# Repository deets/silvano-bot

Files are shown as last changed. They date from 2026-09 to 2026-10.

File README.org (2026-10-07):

#+STARTUP: inlineimages
* Silvano Bot

Silvano-Bot is a small robotics platform to experiment with.

** Quickstart

 - Power on the robot.
 - Connect to the network =silvano-bot= with your smartphone.
 - After a few seconds, go to http://silvano-bot.local
 - Control the robot using your finger. Adjust the slider on the top
   for the maximum speed.

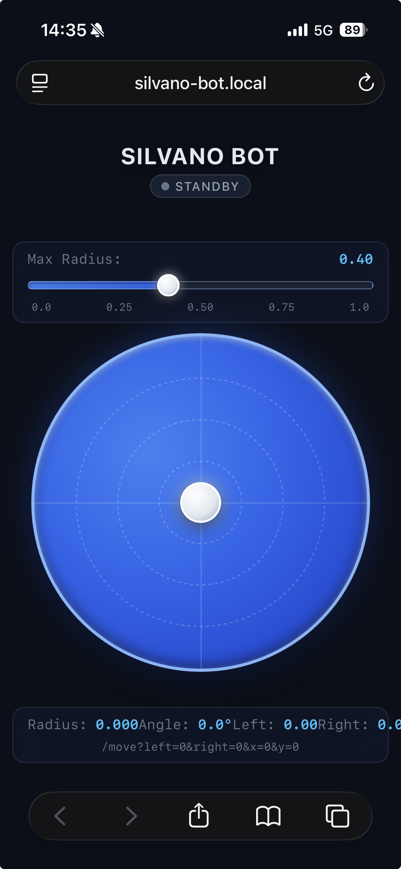
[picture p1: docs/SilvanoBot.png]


*** Issues on Android

I've seen problems connecting to the =silvano-bot.local=-Address on
Android. If that doesn't work, go to http://192.168.71.1/ .

** Hardware Notes

The robot is based on a ESP32 microcontroller (LilyGO ESP32 T3) with a
builtin SSD1306-based 128x64 black/white pixel OLED display.

As drive module we use a MD23 robotics kit. This takes about 12V
input, and offers a set of 5V/SDA/SCL/GND connectors. These are used
to connect and power the ESP32.

*Attention*: the ESP32 is a 3.3 volt system! The MD23 is 5 volt
based. The connection used is [[https://learn.adafruit.com/working-with-i2c-devices/overview][I2C bus]] which must be driven to the
respective voltages. So we can't directly connect. Because of this a
[[https://www.adafruit.com/product/1875][level shifter]] (different model, but same features) is used to convert.

** Software Notes

There is two sets of software that show how to work with the robot:

 - [[file:README.org][Rust ESP IDF based.]]
 - [[file:micropython-firmware/README.org][Micropython based.]]

The fully featured one is the one in Rust.

** LilyGO ESP32 T3 LoRa Dev Kit

The LilyGO ESP32 T3 LoRa Dev Kit is a breakout board with an ESP32,
USB-micro connector, a 433MHz LoRa module and a small 128x64 OLED
display.

The LoRa module is not used in this robot.

*** Pinout

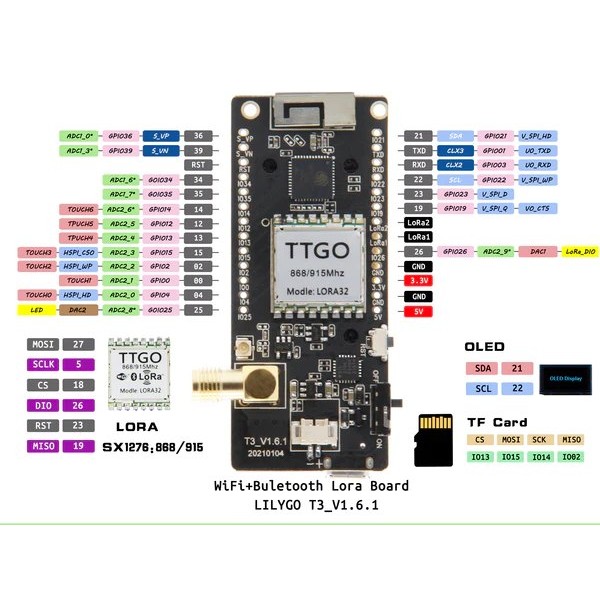
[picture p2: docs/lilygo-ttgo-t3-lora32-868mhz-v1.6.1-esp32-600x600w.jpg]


*** Pin Assignment

We use two I2C buses, one for the OLED, and one for the MD23. These
are their pins.

|-----+-------------|
| Pin | Function    |
|-----+-------------|
|  13 | SDA MD23    |
|  14 | SCL MD23    |
|-----+-------------|
|  21 | SDA Display |
|  22 | SCL Display |
|-----+-------------|

** MD23 Robotics Kit

The MD23 robotics kit a a bundle of two motors with encoders and a
control PCB. See [[file:docs/m=][the documentation]] for a full description of the
features.

It accepts about *12V* as input voltage and provides a I2C + 5V/GND
connector array.

*Important*: the documentation doesn't state this clearly, but the
device only operates at *100KHz* I2C bus frequency! If you use the very
common 400KHz, you will observer random errors. Learned that the hard
way.

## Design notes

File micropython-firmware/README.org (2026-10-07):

* Micropython Firmware

The Micropython (mPy) firmware can operate the MD23 kit. It does currently
not operate the display.

For performance reasons, the implementation is split into two:

 - the mPy code itself, that just listens to two incoming bytes,
   left/right speed.
 - A [[file:server.py][server side script]] that must run on e.g. a laptop to display the
   web-interface and send control commands via socket.

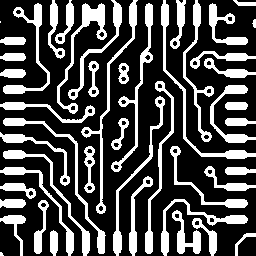
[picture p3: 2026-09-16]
assets/pcb.png

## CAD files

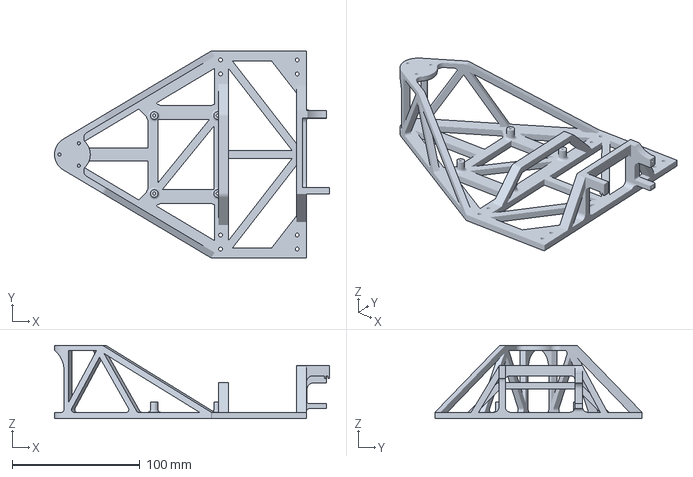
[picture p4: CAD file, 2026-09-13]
cad-data/chassis.3mf
215.1 x 162.0 x 57.4 mm

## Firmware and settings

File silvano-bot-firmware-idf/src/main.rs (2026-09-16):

use std::sync::{Arc, Mutex};

use display::SilvanoBotDisplay;
use esp_idf_svc::{
    eventloop::EspSystemEventLoop,
    hal::{
        delay::FreeRtos,
        i2c::{I2cConfig, I2cDriver},
        peripherals::Peripherals,
        units::*,
    },
    http::{Method, server::EspHttpServer},
    io::Write,
    mdns::EspMdns,
    nvs::EspDefaultNvsPartition,
    wifi::{self, AccessPointConfiguration, AuthMethod, BlockingWifi, EspWifi},
};

use log::info;
use movement::{Movement, MovementController, parse_query_string_for_motor_movement};

mod display;
mod eyes;
mod movement;

const SSID: &str = "silvano-bot";
const CHANNEL: u8 = 11;
const INDEX_HTML: &[u8] = include_bytes!("../../assets/index.html");

fn main() -> eyre::Result<()> {
    // It is necessary to call this function once. Otherwise, some patches to the runtime
    // implemented by esp-idf-sys might not link properly. See https://github.com/esp-rys/esp-idf-template/issues/71
    esp_idf_svc::sys::link_patches();

    // Bind the log crate to the ESP Logging facilities
    esp_idf_svc::log::EspLogger::initialize_default();
    let peripherals = Peripherals::take().expect("Can't create Peripherals");

    let sys_loop = EspSystemEventLoop::take()?;
    let nvs = EspDefaultNvsPartition::take()?;

    let mut wifi = BlockingWifi::wrap(
        EspWifi::new(peripherals.modem, sys_loop.clone(), Some(nvs))?,
        sys_loop,
    )?;
    connect_wifi(&mut wifi)?;

    let movement_command = Arc::new(Mutex::new(None));
    let server_movement_command = movement_command.clone();
    let mut server = create_server()?;

    server.fn_handler("/", Method::Get, |req| {
        req.into_ok_response()?.write_all(INDEX_HTML).map(|_| ())
    })?;
    server.fn_handler("/move", Method::Get, move |req| {
        let mut movement_guard = server_movement_command
            .lock()
            .expect("Can't lock movement_command");
        *movement_guard = parse_query_string_for_motor_movement(Some(req.uri()));
        req.into_ok_response().map(|_| ())
    })?;

    // Setup mDNS
    let mut mdns = EspMdns::take()?;
    mdns.set_hostname("silvano-bot")?;
    // Advertise the HTTP server
    mdns.add_service(Some("Silvano Bot HTTP Server"), "_http", "_tcp", 80, &[])?;

    let i2c = peripherals.i2c1;
    let sda = peripherals.pins.gpio21;
    let scl = peripherals.pins.gpio22;

    let config = I2cConfig::new().baudrate(400.kHz().into());
    let display_i2c = I2cDriver::new(i2c, sda, scl, &config)?;

    let config = I2cConfig::new().baudrate(100.kHz().into());
    let motor_i2c = I2cDriver::new(
        peripherals.i2c0,
        peripherals.pins.gpio13,
        peripherals.pins.gpio14,
        &config,
    )?;
    let eye_movement = Arc::new(Mutex::new(Movement::default()));
    let mut controller =
        MovementController::new(motor_i2c, movement_command.clone(), eye_movement.clone());
    let mut display = SilvanoBotDisplay::new(display_i2c, eye_movement);
    loop {
        display.update();
        controller.drive()?;
        // we are sleeping here to make sure the watchdog isn't triggered
        FreeRtos::delay_ms(1);
    }
}

fn connect_wifi(wifi: &mut BlockingWifi<EspWifi<'static>>) -> eyre::Result<()> {
    // If instead of creating a new network you want to serve the page
    // on your local network, you can replace this configuration with
    // the client configuration from the http_client example.
    let wifi_configuration = wifi::Configuration::AccessPoint(AccessPointConfiguration {
        ssid: SSID.try_into().unwrap(),
        ssid_hidden: false,
        auth_method: AuthMethod::None,
        password: "".try_into().unwrap(),
        channel: CHANNEL,
        ..Default::default()
    });

    wifi.set_configuration(&wifi_configuration)?;

    wifi.start()?;
    info!("Wifi started");

    wifi.wait_netif_up()?;
    info!("Wifi netif up");

    info!("Created Wi-Fi with WIFI_SSID `{SSID}`");

    Ok(())
}

const STACK_SIZE: usize = 10240;
fn create_server() -> eyre::Result<EspHttpServer<'static>> {
    let server_configuration = esp_idf_svc::http::server::Configuration {
        stack_size: STACK_SIZE,
        ..Default::default()
    };

    Ok(EspHttpServer::new(&server_configuration)?)
}

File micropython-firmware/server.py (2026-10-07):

#!/usr/bin/env python3
"""
Silvano Bot Pure Python Web Server

- Opens on port 8080 (configurable via CLI).
- Serves the project's index.html.
- Under /move?left=<float>&right=<float>, converts floats in [-1.0, 1.0] to
  integers mapping -1.0 -> 0 and 1.0 -> 255.
- Sends these two bytes to a socket connecting to 192.168.4.1:80.
"""

import argparse
import json
import logging
import os
from pathlib import Path
import select
import socket
import sys
import threading
from http.server import HTTPServer, BaseHTTPRequestHandler, ThreadingHTTPServer
from urllib.parse import urlparse, parse_qs

# Configure logging
logging.basicConfig(
    level=logging.INFO,
    format="[%(asctime)s] %(levelname)s: %(message)s",
    datefmt="%H:%M:%S",
)
logger = logging.getLogger("silvano_server")


def float_to_byte(val: float) -> int:
    """
    Map a float in [-1.0, 1.0] to an integer in [0, 255].
    -1.0 maps to 0, 1.0 maps to 255, and 0.0 maps to 128.
    Values outside [-1.0, 1.0] are clamped.
    """
    clamped = max(-1.0, min(1.0, float(-val)))
    scaled = (clamped + 1.0) / 2.0 * 255.0
    return max(0, min(255, int(round(scaled)))) >> 1


def find_index_html(custom_path: str | None = None) -> Path:
    """Locate index.html in the project tree."""
    if custom_path:
        p = Path(custom_path).resolve()
        if p.is_file():
            return p
        raise FileNotFoundError(f"Specified HTML file not found: {custom_path}")

    base_dir = Path(__file__).resolve().parent
    candidates = [
        base_dir / "../assets" / "index.html",
    ]
    for candidate in candidates:
        if candidate.is_file():
            return candidate

    matches = list(base_dir.rglob("index.html"))
    if matches:
        return matches[0]

    raise FileNotFoundError("Could not locate index.html in project directory.")


class RobotSocketClient:
    """
    Manages the socket connection to the robot (target_ip:target_port).
    Maintains a persistent TCP connection when supported, and reconnects
    cleanly if disconnected or closed by the remote host.
    """

    def __init__(self, host: str = "192.168.4.1", port: int = 80, timeout: float = 1.0):
        self.host = host
        self.port = port
        self.timeout = timeout
        self._sock: socket.socket | None = None
        self._lock = threading.Lock()

    def _close(self):
        if self._sock is not None:
            try:
                self._sock.close()
            except Exception:
                pass
            self._sock = None

    def _is_closed(self) -> bool:
        if self._sock is None:
            return True
        try:
            # Check if socket has pending data or closed by remote (EOF)
            r, _, _ = select.select([self._sock], [], [], 0)
            if r:
                data = self._sock.recv(1, socket.MSG_PEEK)
                if not data:
                    return True
            return False
        except Exception:
            return True

    def send(self, data: bytes):
        """
        Send raw bytes to the robot socket.
        Automatically reconnects if the connection was closed.
        """
        with self._lock:
            if self._is_closed():
                self._close()

            # Attempt to send; retry once with a fresh connection if stale
            for attempt in range(2):
                if self._sock is None:
                    try:
                        s = socket.socket(socket.AF_INET, socket.SOCK_STREAM)
                        s.settimeout(self.timeout)
                        s.setsockopt(socket.IPPROTO_TCP, socket.TCP_NODELAY, 1)
                        s.connect((self.host, self.port))
                        self._sock = s
                    except Exception as e:
                        self._close()
                        raise e

                try:
                    self._sock.sendall(data)
                    return
                except Exception as e:
                    self._close()
                    if attempt == 1:
                        raise e

    def close(self):
        with self._lock:
            self._close()


class SilvanoRequestHandler(BaseHTTPRequestHandler):
    html_path: Path
    robot_client: RobotSocketClient

    def log_message(self, format, *args):
        logger.info("%s - %s", self.address_string(), format % args)

    def do_GET(self):
        parsed = urlparse(self.path)
        path = parsed.path

        if path in ("/", "/index.html"):
            self.handle_index()
        elif path == "/move":
            self.handle_move(parsed.query)
        elif path == "/favicon.ico":
            self.send_response(204)
            self.end_headers()
        else:
            self.send_error(404, "Not Found")

    def handle_index(self):
        try:
            with open(self.html_path, "rb") as f:
                content = f.read()
            self.send_response(200)
            self.send_header("Content-Type", "text/html; charset=utf-8")
            self.send_header("Content-Length", str(len(content)))
            self.send_header("Cache-Control", "no-cache")
            self.end_headers()
            self.wfile.write(content)
        except Exception as e:
            logger.error("Failed to read index.html: %s", e)
            self.send_error(500, f"Error reading index.html: {e}")

    def handle_move(self, query_str: str):
        params = parse_qs(query_str)
        try:
            left_val = float(params.get("left", ["0.0"])[0])
            right_val = float(params.get("right", ["0.0"])[0])
        except (ValueError, TypeError) as e:
            self.send_json_response(400, {
                "status": "error",
                "message": f"Invalid float parameters: {e}"
            })
            return

        left_byte = float_to_byte(left_val)
        right_byte = float_to_byte(right_val)

        payload = bytes([left_byte | 0x80, right_byte])
        try:
            self.robot_client.send(payload)
            logger.debug("Sent to robot: left=%d (0x%02x), right=%d (0x%02x)",
                         left_byte, left_byte, right_byte, right_byte)
            self.send_json_response(200, {
                "status": "ok",
                "left": left_byte,
                "right": right_byte,
            })
        except Exception as e:
            logger.warning("Failed to send movement to robot (%s:%s): %s",
                           self.robot_client.host, self.robot_client.port, e)
            self.send_json_response(502, {
                "status": "error",
                "message": f"Failed to send to robot at {self.robot_client.host}:{self.robot_client.port}: {e}",
                "left": left_byte,
                "right": right_byte,
            })
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

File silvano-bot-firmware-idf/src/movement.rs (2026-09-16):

use std::{
    sync::{Arc, Mutex},
    time::{Duration, Instant},
};

use esp_idf_svc::hal::i2c::{I2cDriver, Operation};

#[derive(Debug, Clone, Copy, PartialEq, Default)]
pub struct Movement {
    pub left: f32,
    pub right: f32,
    pub x: f32,
    pub y: f32,
}

pub fn parse_query_string_for_motor_movement(path: Option<&'_ str>) -> Option<Movement> {
    let path = path?;
    let query = path.split_once('?').map_or(path, |(_, q)| q);
    let query = query.split_once('#').map_or(query, |(q, _)| q);

    let mut left = None;
    let mut right = None;
    let mut x = None;
    let mut y = None;

    for pair in query.split('&') {
        if pair.is_empty() {
            continue;
        }
        if let Some((key, val)) = pair.split_once('=') {
            match key.trim() {
                "left" => {
                    left = Some(decode_float(val)?);
                }
                "right" => {
                    right = Some(decode_float(val)?);
                }
                "x" => {
                    x = Some(decode_float(val)?);
                }
                "y" => {
                    y = Some(decode_float(val)?);
                }
                _ => {}
            }
        }
    }

    match (left, right, x, y) {
        (Some(left), Some(right), Some(x), Some(y)) => Some(Movement { left, right, x, y }),
        _ => None,
    }
}

fn decode_float(s: &str) -> Option<f32> {
    s.parse::<f32>().ok()
}

pub struct MovementController<'a> {
    bus: I2cDriver<'a>,
    last_update: Instant,
    command: Arc<Mutex<Option<Movement>>>,
    eye_movement: Arc<Mutex<Movement>>,
}

const MD23_ADDRESS: u8 = 0x58;
const MD23_LEFT: u8 = 1;
const MD23_RIGHT: u8 = 0;
const MD23_ENC1: u8 = 2;
const MD23_ENC2: u8 = 6;
const MD23_MODE: u8 = 15;

pub struct MD23State {
    /// The values we've written the last time we
    /// actively controlled the motors
    pub control: (u8, u8),
    /// The read back actual speed values
    pub speeds: (u8, u8),
    /// Encoders read the last time
    pub encoders: (i32, i32),
}

impl<'a> MovementController<'a> {
    pub fn new(
        bus: I2cDriver<'a>,
        command: Arc<Mutex<Option<Movement>>>,
        eye_movement: Arc<Mutex<Movement>>,
    ) -> Self {
        Self {
            bus,
            last_update: Instant::now(),
            command,
            eye_movement,
        }
    }

    pub fn drive(&mut self) -> eyre::Result<()> {
        let movement = self
            .command
            .lock()
            .map_err(|_| eyre::eyre!("Can't lock"))?
            .take();
        if let Some(movement) = movement {
            self.last_update = Instant::now();
            *self.eye_movement.lock().unwrap() = movement.clone();
            self.set_motor(movement.left, movement.right)?;
        }
        if self.last_update.elapsed() > Duration::from_millis(500) {
            self.set_motor(0.0, 0.0)?;
        }
        Ok(())
    }

    fn set_motor(&mut self, left: f32, right: f32) -> eyre::Result<()> {
        let left = (-left * 127.0 + 128.0) as u8;
        let right = (-right * 127.0 + 128.0) as u8;
        self.set_register_u8(MD23_LEFT, left)?;
        self.set_register_u8(MD23_RIGHT, right)
    }

    fn set_register_u8(&mut self, reg: u8, value: u8) -> eyre::Result<()> {
        self.bus
            .transaction(
                MD23_ADDRESS,
                &mut [Operation::Write(&[reg]), Operation::Write(&[value])],
                100000,
            )
            .map_err(|_| eyre::eyre!("I2C movement error"))
    }

    // fn read_encoders(&mut self) -> Result<(i32, i32), Error> {
    //     let mut encoder_values = [0; 4];
    //     let _ = self.bus.write_async(MD23_ADDRESS, &[MD23_ENC1])?;
    //     let _ = self.bus.read_async(MD23_ADDRESS, &mut encoder_values)?;
    //     let left = i32::from_be_bytes(encoder_values);
    //     let _ = self.bus.write_async(MD23_ADDRESS, &[MD23_ENC2])?;
    //     let _ = self.bus.read_async(MD23_ADDRESS, &mut encoder_values)?;
    //     let right = i32::from_be_bytes(encoder_values);
    //     Ok((left, right))
    // }

    // fn read_speeds(&mut self) -> Result<(u8, u8), Error> {
    //     Ok((
    //         self.read_register_u8(MD23_LEFT)?,
    //         self.read_register_u8(MD23_RIGHT)?,
    //     ))
    // }

    // fn read_register_u8(&mut self, reg: u8) -> Result<u8, Error> {
    //     let mut value = [0; 1];
    //     let _ = self.bus.write_async(MD23_ADDRESS, &[reg]);
    //     let _ = self.bus.read_async(MD23_ADDRESS, &mut value);
    //     Ok(value[0])
    // }
}

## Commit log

2026-09-13 Compute the left/right motor settings
2026-09-13 Movement with async i2c
2026-09-13 Change the way last encoder and speed values are determined
2026-09-13 Latest chassis
    [chassis.3mf]
2026-09-13 Spin the motors
2026-09-13 Use 100KHz for MD23
    It appears as if the MD23 can only really stomach 100KHz. Found
    that out using micropython, so I keep that one around for
    fast experiments or a switch in the future
2026-09-13 Rework to automatically stop after 0.5s
    [main.py]
2026-09-13 Got a micropython thing working
    Turns out processing full HTTP requests is way too slow, at least
    with my primitive approach.
    I assume a websocket would be more robust.
    It also shows that esp-hal is not fit for the task (as they said so
    for the ESP32s)
    I *might* move to esp-idf-hal, or C++.
    [main.py, server.py]
2026-09-15 Add PCB image as PCB
2026-09-16 Introduce a moving PCB background
2026-09-16 Show the googly eyes on the robot and the PCB background
